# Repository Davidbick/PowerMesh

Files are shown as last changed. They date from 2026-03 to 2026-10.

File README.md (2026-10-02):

# PowerMesh: PLC Smart Home
PowerMesh is a smart home system that uses power line communication (PLC) instead of Wi-Fi to connect devices, enabling more stable and secure control over existing electrical wiring. It integrates Matter and Home Assistant to support cross-platform device control while exploring IP-based communication over power lines. 

## Project Architecture 
PowerMesh leverages PLC communication to integrate a Matter-based protocol built atop IEEE 1901.2. The user via our protocol can communication with one of our "hubs" to control an LED bulb at the other end of the Powerline.

Our user interacts with Home Assistant which transfers the commands via the ST8500 and STLD1 chips. The commands control the state of the endpoint lightbulbs and has the option to scale to various other receiver hubs connected to the powerlines.

## Task Designation:

1) PCB Design : Bryan, Daniel
- **Goal:** Contribute to PCB design of the PLC hub on the analog and digital boards to create a complete board design with both aspects.

2) Perf Board, ST IC Prototyping: Logan, David
- **Goal:**  Have code functionality with ST8500 and STLD1 chips using the STM32F4 so to have groundwork for software integration on PCB.

3) Home Assistant Setup: Steven
- **Goal:**  Have the Home Assistant platform working with STM32 and temporary endpoint (RPI4) to seemlessly integrate into design.

## Completed Work: Pre-Alpha Build

- Principal component research. We've narrowed our options to the ST8500 and STLD1 chips that powered a ST PLC development board.
- We've started PCB design on the hub infrastructure. Mostly on the digital side of the board with the STM32F4, ST8500, and STLD1.
- Started STM32 bring-up by writing and testing basic code for UART and peripherals without having the final hardware. Also planned out how the STM32 will communicate with the ST8500.

## Completed Work: Design Prototype
- We've completed schematic design for our analog and digital board with plans to complete layout before the beginning of next semester.
- We've integrated Home Assistant wirelessly with our RaspberryPi host device with plans to complete wired integration with an LED circuit.
- We've narrowed our software scope to the G3 stack after ST confirmed indirect IEEE 1901.2 compatibility. We'll have ST8500 integration before the beginning of next semester.

## Completed Work: Beta Build
- Home Assistant TUN interface
- PCB Digital Designs
- PCB Analog Designs

# Build Instructions
- Install Home Assistant OS on RaspberryPi, and connect GPIO pins to the appropriate serial protocol
- Use local address of Home Assistant server to visit Webpage and control added Home Assistant devices

# List of Known Bugs:
- PLC functionality has yet to be thoroughly tested with other components which will be a large endeavor
- The TUN interface and the Raspberry Pi-to-STM32 bridge currently require manual startup after the Raspberry Pi boots.
- STM32-to-ST8500 communication has not yet been integrated into the PowerMesh packet path.

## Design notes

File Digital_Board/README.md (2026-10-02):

# PowerMesh: PLC Home Digital PCB

This folder contains information related to the digital parts of the PLC hub board; more specifically the non coupler circuitry.

## Files
- `Digital_Board` contains the KiCad design files for Schematic and PCB layout
- `General_ST_Docs` contains ST chip information that would be useful to navigate the project
- `Programming_Docs`: Programming Docs on how to program the chip

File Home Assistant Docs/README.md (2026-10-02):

# Home Assistant

Home Assistant (HA) is an open-source software that will act as the hub to connect with the smart devices. We have Raspberry Pi OS x64 for the RPI3 on our microSD. From the RPI OS, we have a HA Docker.

## How it will be implemented

Using the RPI3 of the previous group, a microSD card housing HA Docker using RPI OS will be inserted into the RPI3. The RPI3 will be powered on using a micro USB and an ethernet cable will be connected to the RPI3 and a router. Once everything is connected, powered on, and the configuration is all set, the HA dashboard can be accessed. Commands will be sent via HA, and the statuses of the smart devices connected will also be sent to HA via the RPI hub. This should be done via using the Matter standard.

## Current bugs

- MicroSD we are using might be degrading. It was having write problems when trying to install RPI OS x64.

## Work completed

- Able to send a command from HA to a Matter-enabled smart bulb, which changed its color (Matter over Wi-Fi)
- Migration to RPI OS x64
- Design of Matter transportation

## Planned work

- Make RPI3 send the command out through UART instead of Wi-Fi (might have to disable Bluetooth, which might cause a problem for comissioning new Matter-enabled smart devices on to HA)
- Connect the RPI3 and STM32 via SPI so that the RPI3 sends the command to the STM32
- Get a ESP32 S3 dev kit that has enough RAM to store the Matter SDK via esp-matter. This will act as a DIY Matter-enabled smart bulb. Turn off wireless capabilities except Bluetooth (used for comissioning new smart devices). Test if Matter commands can control the RGB LED on it via PWM

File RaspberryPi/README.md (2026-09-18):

# PowerMesh Raspberry Pi Bridge

This directory contains the Raspberry Pi side of the PowerMesh transport.

It bridges Linux IPv6 traffic from a TUN interface to the STM32 using the existing PowerMesh UART framing protocol.

## Setup

Clone the repository on the Raspberry Pi:

```bash
cd ~
git clone https://github.com/Davidbick/PowerMesh.git
cd PowerMesh
```

Install the required Python support:

```bash
sudo apt update
sudo apt install -y python3-venv
```

Create the virtual environment and install dependencies:

```bash
python3 -m venv RaspberryPi/.venv

RaspberryPi/.venv/bin/pip install \
    -r RaspberryPi/requirements.txt
```

## Connect the STM32

Connect the STM32/Nucleo to the Pi over USB.

Find its serial port:

```bash
ls -l /dev/serial/by-id/
```

or:

```bash
ls /dev/ttyACM*
```

If serial permissions fail:

```bash
sudo usermod -aG dialout "$USER"
```

Then log out and back in or reboot.

## Create the TUN Interface

Make the setup script executable once:

```bash
chmod +x RaspberryPi/setup_tun.sh
```

Run:

```bash
./RaspberryPi/setup_tun.sh
```

This creates:

```text
Interface:  powermesh0
Pi address: fd00:706d::1/64
MTU:        1280
```

Verify:

```bash
ip -6 addr show dev powermesh0
```

and:

```bash
ip -6 route get fd00:706d::2
```

## Run the Bridge

Start the TUN/UART bridge:

```bash
RaspberryPi/.venv/bin/python \
    RaspberryPi/tun_uart_bridge.py \
    /dev/ttyACM0
```

Leave this running.

## Test

From another terminal on the Pi:

```bash
ping -6 fd00:706d::2
```

**The ping will not succeed yet because the STM32 does not currently generate an IPv6 reply.**

The bridge should show:

```text
TUN -> UART: seq=1, <bytes> bytes
UART ACK: seq=1, status=0
```

## Normal Use After Reboot

After rebooting the Pi:

```bash
cd ~/PowerMesh

./RaspberryPi/setup_tun.sh

RaspberryPi/.venv/bin/python \
    RaspberryPi/tun_uart_bridge.py \
    /dev/ttyACM0
```

## Updating

Pull the latest PowerMesh code:

```bash
cd ~/PowerMesh
git pull --ff-only
```

## Current Status

PowerMesh currently supports:

```text
Matter Server / Linux IPv6
        ↓
powermesh0 TUN
        ↓
Python TUN-UART bridge
        ↓
STM32
        ↓
UART ACK

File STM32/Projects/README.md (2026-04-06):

# STM32 Bring-Up

This sets up the NUCLEO-F446RE environment.

## What This Does

- Builds STM32 project using **CMake + VSCode**
- Verifies:
  - LED blink
  - UART transmit

## Required Tools

Install the following:

- STM32CubeMX
- arm-none-eabi-gcc
- CMake
- VSCode + Extensions
  - C/C++, CMake Tools, Cortex-Debug
- OpenOCD
- STM32CubeProgrammer

## Build Instructions

From project root:

```
cmake --preset Debug
cmake --build --preset Debug
```

## Hardware Test (When Board Arrives)

1. Plug in NUCLEO-F446RE via USB  
2. Start debug in VSCode  
3. Verify:
   - Breakpoint at `main()` works  
   - LED blinks  
   - UART prints over serial terminal  

- Next steps:
  - SPI bring-up  
  - STM32 ↔ ST8500 communication

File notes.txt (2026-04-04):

# PowerMesh Smart Home

Task Designation:

1) PCB Design : Bryan, Daniel
- Goal: Have progress on the PCB design aspects of the project so that we can present either a complete schematic or a thorough prototype so that we can order it first thing 2nd semester.,
- I'm planning on having an STM32 board and a PLC board with the ST8500 and the STLD1 chips that will house the coupling circuit.,
- I think splitting both boards would be a good idea so Daniel can likely work on the PLC board and I'll join once I finish the STM32 board which should be easier.,

2) ST setup: Logan, David
- Start communication between the 3 st chips using the PERF boards robert bought/already has.,
- Connect to the STM devboards and try to drive the ST8500 and the STLD1. While we won't be connected to the powerlines we can test functionality of the chips and start designing aspects of the coupling circuit potentially.,
- Goal: Have basic code functionality with the stm chips so that we can re-use that code on the final design with the PCB or in a robust breadboard testing.,

3) Home Assistant Setup: Steven
- Goal: Have the Home Assistant platform already working but with STM32 so we can just swap in the code once we get the PLC stuff working.,
- Specific Goals: Connect STM32 to Rpi4 with any serial communication (not sure if this will be the final method), Have home assistant interact with the bulb already MAYBE( might be harder than expected but we have bulbs to use).,
- This also allows someone to get substantial work done with the STM32 Nucleo and the Rpi4 that the last team left.,
- Dr. Del Rocco mentioned Home Assistant and I figured we could start work on this so we can have something substantial to show in the presentation.
- The benefit with on working with this, is once the nucleo arrives you should have everything to work on this.

For the STM32 development the workflow I'm familiar with is through vscode but if you want to use a different IDE that's okay, I just don't know what's going on with those.
The stuff you need is:

-STM32MX: This is the code generator with a GUI interface that is used for the ST MCUs. You should be able to choose our stm32f4 MCU and then it'll generate the code based on the peripherals you selected in the .ioc file. This should be a standalone download and make sure to use cmake as the build system at the last page before "generating project". You should be able to generate your .elf file this way.

OpenOCD: This is the server that you'll instantiate on your PC to communicate with the debugger on the nucelo board. There should be installation settings on their website. In Vscode you should be able to use the config files in the.vscode folder to run the openocd server and connect the debugger.

If you're debugging in VScode I recommend using the cortex-debug extension to set all this up. I've done this on linux a couple times but never on windows so I might be useless there. You should be able to connect to any IDE with Cmake and it gets rid of all that stmcubeide abstraction so you understand what's going on better.

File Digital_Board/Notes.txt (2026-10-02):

- VSS is the digital ground, VSSA is the Analog ground (DAC/ADC)
    -Not sure what the requirement is for this, aka will we need this? Look at the evalboard

-VDD is +3.3V for the MCU. VBAT is something else with an external battery but we can use +3.3v for it.

-Decoupling capacitors are used to place small energy storages along the MCU so that it doesn't rely on main battery.
    - 1 Decoupling-capa(100n F) per VBAT and VDD. Extra 10 uF at the end (volt decoupling)

-WTF is a fertite bead

- Look at the SPDT more for the BOOT0. I'm not exactly sure how this works.

- DO WE NEED USB if we have the UART?

-24 MHz for USB, just in case? FINISH OSCILLATOR

- Why is the USB shield NC/
-Check USB for resistors that I see on all other designs.

-GPIO6/7 are the RX and TX (HOST_IF1-4 are the UART)
    - Use USART2 asynchonrous on our design

- Add ferite bead to the regulator to reduce noise

-

Questions:
 - What is the UART/USB bridge for if USB is connected to the microcontroller?

TODO:
1) Confirm the Pitch for the STM32 microcontrollers
2) The Oscillator capactiors are WRONG!!!!

Slide 7:
	-Project is in the realm of research
	- PLC standards are not new, and are still widely used for smart metering technologies
	- However the standards have been largely dormant since the early 2010s. Which is in-line with the various ST chip options and their respective development kits.
	
	- Prior X10 adapters were a home standard for PLC communication between devices. But when wireless technologies blew up they rapidly shortened their usage.
	- Existing standards are G3-PLC, PRIME, and IEEE 1901.2
		- Difference is IEEE 1901.2 is lower stack protocol compared to GL3 that does RF communication

Slide 8:
	- Our initial research focused on research on the available resources and how to integrate them into our hub system.
	- Matter and Home Assistant are wide spread technologies which are tested we need to apply both of them.
	
	- The current state of the project is split into multiple groups: PCB design, software integration, and application design with HA
	- Our done metrics are the entirety of the research and schematic design for the separate boards. With software integration for our chosen chipset.
	
Slide 9:
	- Not going to go through everything but main aspects of thedigital board.
		- SWD for debugging
		- 2 UART channels as per existing EVAL kits
		- USBC for any integration with a desktop computer
		- External oscillator
	- STM32 to St8500 male pins
	- Access to SPI and I2C channels in case
	- Basics like reset buttons and LEDs

Pawpilot:
-

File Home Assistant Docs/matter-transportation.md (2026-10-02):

# Matter Transportation
There are various ways to transport the Matter payload to the Matter enabled end-device. Here are some options and some possible notes on how to implement them using the resources we have.

## Option 1: Create Matter Payload at the End
1. Capture the Home Assistant (HA) command that will be turned into a JSON. This would mean capturing the Matter Server WebSocket API [GitHub Documentation.](https://github.com/matter-js/matterjs-server/blob/main/docs/websockets_api.md?utm_source=chatgpt.com) This could be accomplished by using a proxy between HA and the Matter server, since the Matter server constructs the Matter payload.
2. Parsing of the command might be needed. Some essential fields to keep are node_id, endpoint_id, cluster_id, command_name, and payload (along with its contents). Others may also be necessary. Create the JSON. According to the documentation on point 1, device_command has all of this information.
3. Use a device with Matter SDK to dynamically create a Matter payload using the JSON.
4. For the Matter payload to actually get on the end-device, use an ethernet cable or make the end-device be the device that create the Matter payload for itself.

## Option 2: Point to Point Protocol (PPP)
1. Get Home Assistant on the RPI3 using linux. HA OS would have resitrictions that would make having PPP to automatically frame the Matter payload difficult.
2. Matter is IPv6. Use PPP to frame those IPv6 packets so that it can be sent serially, like through UART. Can also be used with SPI, but SPI is naturally more difficult. PPP essentially frames the IPv6 packets that contains the Matter payload.
3. Use UART to send the framed IPv6 packets from the RPI3 to the STM32.
4. Use UART/SPI to keep transporting everything. Besides the end-device, everything should just be transport.
5. Since we framed the IPv6 packets, it would have to be deframed somewhere. This would be at the end.

## Option 3: Ethernet Cable Everything
1. Simply have all devices have ethernet ports to transport the Matter payload, since Matter commands can be transported using ethernet. Also solves problems with Matter multicast (RPI3 communicating with multiple devices) and discovery (mDNS to announce that the device is back if power goes out). Makes sure that everything can handle IPv6 and ethernet compatibility.

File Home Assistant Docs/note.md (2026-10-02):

# Note
This file contains information about Home Assistant, how it is used, and how it works with our hardware.

## HA Initialization
When RPI is ready, enter this in a browser:
"http://\<RPI3_ADDRESS>:8123"
If white screen with HA logo, enter this in a browser:
"http://\<RPI3_ADDRESS>:4357"
If everything is green, then the RPI is being bottlenecked due to its limitations. Wait like 20 minutes before entering the other URL into a browser (close all HA instances so that the browsers won't take resources from the RPI).

## Adding Devices (old)
Adding matter device
open HA app -> settings -> device & services -> Search and select "Matter" -> use official matter server (box selected) -> scan QR code or hold phone near Matter device -> device should be connected after naming it

## Adding Home Assitant Docker to Raspberry Pi OS x64 (for RPI3) (CURRENT)
# Getting Raspberry Pi OS on a microSD
1. Select Device, OS, storage, create an account, and setup localisation
2. Skip Wi-Fi
3. Enable SSH
4. Write to the MicroSD

# Getting Docker (run these commands)
1. sudo apt update
2. sudo apt install ca-certificates curl
3. sudo install -m 0755 -d /etc/apt/keyrings
4. sudo curl -fsSL https://download.docker.com/linux/debian/gpg -o /etc/apt/keyrings/docker.asc
5. sudo chmod a+r /etc/apt/keyrings/docker.asc
6. echo \
  "deb [arch=$(dpkg --print-architecture) signed-by=/etc/apt/keyrings/docker.asc] https://download.docker.com/linux/debian \
  $(. /etc/os-release && echo "$VERSION_CODENAME") stable" | \
  sudo tee /etc/apt/sources.list.d/docker.list > /dev/null
7. sudo apt update
8. sudo apt install docker-ce docker-ce-cli containerd.io docker-buildx-plugin docker-compose-plugin
9. sudo docker run hello-world
10. You should get "Hello from Docker!" from step 9 if Docker is working.

# Getting HA (run these commands and follow instructions)
1. mkdir -p ~/homeassistant/config
2. mkdir -p ~/homeassistant/matter-server
3. cd ~/homeassistant
4. nano ~/homeassistant/compose.yaml
5. In the opened file, put the contents of compose_yaml.txt, which is found in the GitHub repo in the same directory as this Markdown file.
6. Save (ctrl + s) and exit (ctrl + x)
7. cd ~/homeassistant
8. sudo docker compose up -d
9. sudo docker compose ps
10. The previous command should show that HA is running. If there is a message about Bluetooth, ignore it.
11. In a broswer, type in "http://\<RPI3_ADDRESS>:8123". You can use "hostname -I" to find the address in the SSHed terminal, which should be the first one.
12. Use "sudo shutdown -h now" to turn off the Pi when shutting it down.

# Getting Matter Server (run these commands and follow instructions)
1. mkdir -p ~/homeassistant/matter-server
2. nano ~/homeassistant/matter-server/compose.yaml
3. In the opened file, put the contents of matter_server_compose_yaml.txt, which is found in the GitHub repo in the same directory as this Markdown file.
4. cd ~/homeassistant/matter-server
5. sudo docker compose up -d
6. sudo docker compose ps
7. The previous command should show that matterjs-server is running.
8. sudo docker compose logs -f
9. Previous command shows logs for the matter server. Do (ctrl + c) to exit logs.
10. sudo docker logs matterjs-server
11. If the previous command show that the matter server is failing due to "EACCESS: permission denied" do the following (or skip to 18):
12. cd ~/homeassistant/matter-server
13. sudo docker compose down
14. ls -ld ~/homeassistant/matter-server/data
15. docker run --rm --entrypoint id ghcr.io/matter-js/matterjs-server:latest
16. Take note of the uid and gid.
16. sudo chown -R \<UID>:\<GID> ~/homeassistant/matter-server/data
17. If there is no ~/homeassistant/matter-server/data, make it. (mkdir -p ~/homeassistant/matter-server/data), then sudo chown -R \<UID>:\<GID> ~/homeassistant/matter-server/data
18. cd ~/homeassistant/matter-server
19. sudo docker compose up -d
20. sudo docker compose logs -f
21. sudo docker compose ps

# Adding Matter in HA
1. Open HA
2. Settings -> Devices & services -> Add integration
3. Search and click the ones that says "Matter" and wait for it to finish.
4. For the url, put "ws://localhost:5580/ws".

# Debugging
1. No username
If there is no username, it should default to "pi".
For our current project, the username is "powermesh".
2. SSH not responding (please read fully)
In a terminal such as Powershell, do "arp -a". The address should start as 192.168. It could also be something different.
Try to SSH into each one with "ssh \<USERNAME>@\<ADDRESS>".
The address for a Pi should respond with connection refused, while the others will have an unknown error. If multiple has connection refused, use other methods to identify the Pi.
Take out the microSD card and check if it has a file titled "ssh" with no file extension.
If there is no "ssh", correctly add one, which should enable SSH. If the address is still giving problems, use "ipconfig" in a terminal. Get the gateway address, and in a broswer type "http://\<GATEWAY>". This should list all connected devices. The one we are looking for is "PowerMesh". This will show the address for the Pi.

## Adding HA OS to a microSD (DEPRECATED)
RPI Micro SD configuration:
https://www.home-assistant.io/installation/raspberrypi/
Notes from the link:
1. Download RPI Imager and launch it
2. Select RPI3 as device
3. Select Other SPECIFIC-purpose OS (OS Section)
4. Select Home Automation and select Home Assistant (OS Section)
5. There should only be one HA option to choose from. Select it (OS Section)
6. In the storage section, select the Micro SD we are writing it to
7. Click next and it should begin writing HA OS to the Micro SD

## RPI Debugging
RPI Debugging:
1. Check if the RPI is receiving enough power. This can be checked by seeing a constant red LED on the RPI. If it is flickering, the RPI3 is not receiving the constant power it needs.
2. To see if HA is working, look if there is green flickering on the RPI. If there is green flickering, then HA is working.
3. If there is a white screen with HA logo only when doing http://homeassistant.local:8123/, use http://IP_ADDRESS:8123 or the app instead. This is likely due to browser cache issues or hardware limitations of the RPI3.

## HA Companion App
Home Assistant Companion App Download & Instructions:
https://companion.home-assistant.io/docs/getting_started/

Note: This may be for HA OS, and instructions for HA Docker may be different.

### Misc
Home Assistant Green:
https://www.home-assistant.io/green/

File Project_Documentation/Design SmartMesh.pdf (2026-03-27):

### PowerMesh – Design Plan

Project Title: PowerMesh – Matter-over-PLC smart-home infrastructure
Team Members: David Bickram, Steven Pham, Bryan Gonzalez, Logan Dukes, Daniel Goldenberg

Date: 3/24/2026

Terminology:

- PLC → Power Line Communication
- MCU → Microcontroller Unit
- Home Assistant → Open Source Software with Matter Integration. Not to be confused with an actual home assistant like Alexa

### 1. Introduction

### 1.1 Purpose / Need

PowerMesh is a solution to the wireless mesh instability problem. Convenience has been a guiding factor in smart home products, with wireless systems like Thread and Wi-Fi being the most widely adopted technologies. However, the wireless infrastructure isn’t without its faults, with difficulty of installation, network instability, and security concerns being the most prominent.

All these issues are a result of the always-on-network conundrum, where all smart devices must always be connected to the wireless network, and once network issues occur, the entire smart infrastructure goes down. PowerMesh hopes to tackle this by having PLC-based infrastructure that won’t require wireless connectivity, which in return will simplify smart device adoption for consumers by avoiding the barrier of wireless connectivity entirely.

### 1.2 Domain & Prior Art

The field we are specifically targeting is the smart home industry, where wireless technology is prevalent and the product installation is an annoyance. Examples of products in the space are wireless lights (bulbs, strips, and lamps) and home assistants like Alexa.

More specific to our product methodology, PLC technologies that exist but are not often used are X10 connectors [1]. This protocol was a simplified control system for lights in a house. Issues that plagued the technology were a lack of encryption and addressing capabilities, with a limit of 256 devices. This standard is quite antiquated, but it hasn’t been improved upon in decades, so we hope to implement a modern and stable alternative.

### 1.3 Impact & Risk Assessment

Our project will improve societal standards for consumer-grade products by giving consumers control of their smart device networks at home by providing an open hardware and software alternative. We are tackling large infrastructural issues with our project, so potential risks could be compromising consumer security through development oversights or not having reproducible results with the various smart devices in existence, which could limit our adoption.

Economically, our project provides developers with a way to produce low-cost microcontroller systems with existing powerline infrastructure, with those low costs hopefully being reflected in consumer pricing. With our emphasis on using PLC in our project, we are leveraging the existing technology around homes, minimizing the need for new infrastructure that could impact the environment. Social impact is a driving point in our project, specifically encouraging user privacy in our infrastructure as we move away from the more vulnerable wireless systems.

### 2. Statement of Work

### 2.1 Project Overview

### 2.1.1 General Specifications

- Have a PLC-based infrastructure of smart devices that can be remotely controlled via Home Assistant interface with Matter
- Target Smart Device: LED Lightbulbs (aka. multiple receivers)
- The client and server side will use the ST8500 IC to communicate via the powerlines sending data to configure the smart home devices
- Matter: Allows operation of multiple devices from different manufactures such as Google, Apple, and Amazon. [2]. This allows us to integrate with products that dominate the market and new arriving products that will follow suit with Matter.

### 2.2.2 Hardware Requirements

- Client-sided: Use existing smart device circuitry and integrate our custom PLC/ST circuitry into the product, essentially creating our own lightbulb from the existing bulb circuitry. The goal is to have multiple receivers connected to the same transmitter. Uses ST8500 and STM32.
- Server-sided: Integrate PLC/ST circuitry with either a raspberry pi or desktop computer serially. Create a plug-and-play hub with USB. This will communicate with the Home Assistant application to the single/various receivers.
- Networking: Integrate TCP/IP-style communication between devices targeting 3-5 byte per second payload speeds for our LED lightbulb following the IEEE 1901.2 standard. We will be using I2C-style node addressing to communicate with the different receiver nodes using our custom standard.
- Power Consumption: Targeting less than 33kW a year including the LED bulb (13 kW a year) [4] and our ST8500 (20kW) [5]

### 2.1.3 Software Requirements

- MCU:
- Languages: C, C++
- Frameworks: TCP/IP (FreeRTOS/ LWIP), FreeRTOS
- Build Systems: Cmake, Make
- User-Application:
- Languages: Python
- Frameworks: Home Assistant
- General:
- Linux (Debian) for hub system
- ARM cross-compiler targeting ARM Cortex-M ST8500/STM32

### 2.2 Secondary Features

- Thread Integration:Matter supports Thread, which allows for wireless communication with certain devices that our technology could potentially not reach. This allows the possibility of having a smart home using both wired and wireless smart devices.

### 2.3 Milestones and Task Allocation

- Information gathering (This Week & Spring Break)
- Research previous groups efforts
- Determine required hardware components (STM32, STM8500, etc.)
- IEEE 1901.2, Matter, Home Assistant
- Prototype Bring-up (March - April)
- Acquire our hardware development kits (STM-Nucleo/Evalboard)
- Breadboard the basics required for having a communication interconnect between our server and the client prototype smart device
- Have basic Home Assistant integration with some compatible software
- Validation (Throughout Design Process)
- Testing code
- Documentation
- Matter PLC communication standard Design (Fall Semester)

- Final Prototype Targeting (Fall Semester)
- Establish connection with industrial smart bulb and properly control via PLC infrastructure
- Have our smart device rendition PCB
- Thread Integration (Secondary Goal)

### 2.4 Work to Complete This Semester

1) Have a clear demonstration of sending and receiving packets on both endpoints
2) Some sort of client-side equipment functions with received packets
3) Client-side equipment works with transferable interface

### 2.5 Work to Complete At End of Term

1) Multi-colored lightbulb works with packet data
2) Working with Home Assistant
3) Custom PCB integration for lightbulb example
4) Established communication protocol and submit Matter certification

### 3. Deliverable Artifacts

Smart Device Design/Circuitry: This artifact will either be our client hardware connected to the existing circuitry of an LED bulb or a custom LED bulb/hardware that can interact with the hub. Once we are confident in its capabilities, we will integrate it with existing lightbulb technology. The software for the device will be open-source, and the hardware design will be available to replicate on existing Matter smart devices.

Hub Design: The hub design is central for the PLC network; it will control communication between the various devices on the network. With the hub we plan on having a desktop-oriented design for testing purposes, which we’ll move to custom PCB hardware for the final product. For redistributing this hub, we would need to recreate a replica of the hardware, and its software will be open-source.

Home Assistant Interface: This aspect of the project connects the hub and the user-application interface that’ll use Home Assistant with the Matter protocol. This will be usable via a desktop computer or a mobile device. We’ll distribute this via a standard HTTP website that we can test and then improve upon with new plugins. There are no concerns with the Home Assistant software’s availability, as it's constantly being updated, and its plugin flexibility allows people to expand compatibility to their own smart device products.

### 4. Mockups

### 4.1 Interfaces

For PowerMesh, the singular interface is expected to be the Home Assistant control platform running on the hub. The rest of the project will rely on the plug-and-play aspects we hope to create for our users with our hub.

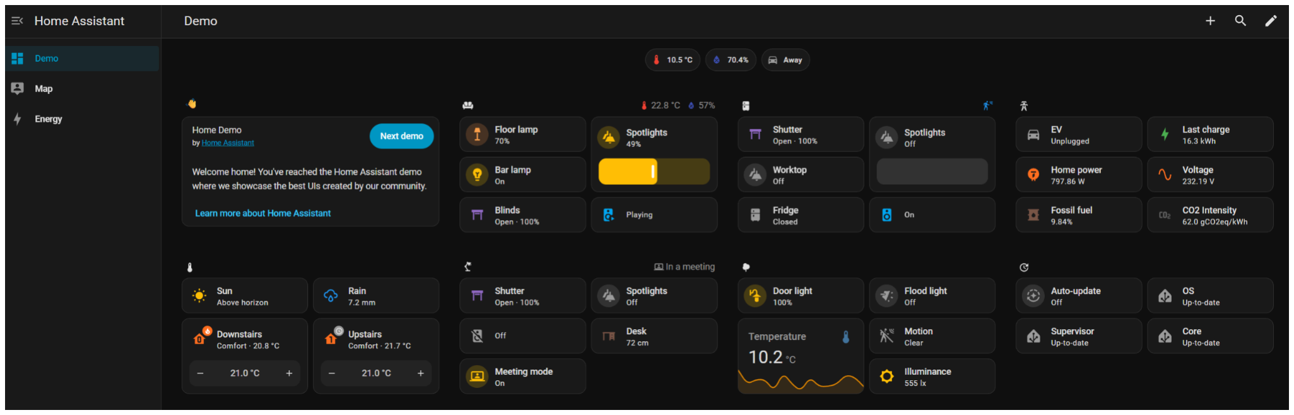
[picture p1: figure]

Figure 1. Home Assistant Dashboard

### 4.2 Systems

The project contains three major subsystems: the hub, the PLC network path, and the
wall node. The hub manages commissioning, user commands, and logging. The PLC path carries framed traffic across the mains and reports link-health data. The wall node hosts the device application and maps it to the transport.

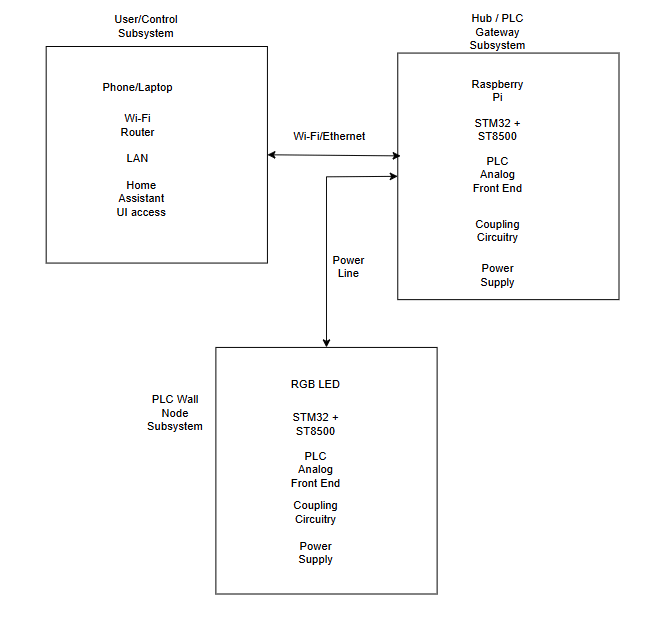
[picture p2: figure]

Figure 2. Subsystem Hardware Components

### 4.3 Networking Model

The PowerMesh networking architecture consists of a hub communicating with embedded wall nodes over PLC, with Home Assistant on the Raspberry Pi serving as the primary control interface. The communication architecture diagram illustrates the end-to-end device interaction across the system, while the protocol layer diagram shows how application commands are translated through the Matter/IP and PLC layers into physical transmissions over the power line network.

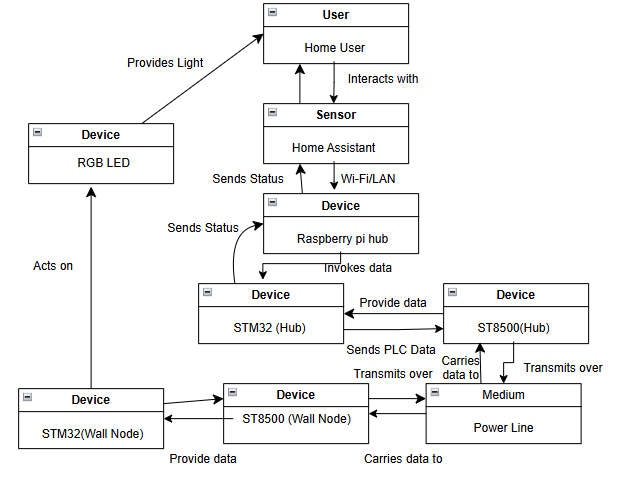
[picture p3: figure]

Figure 3. High Level Communication Architecture

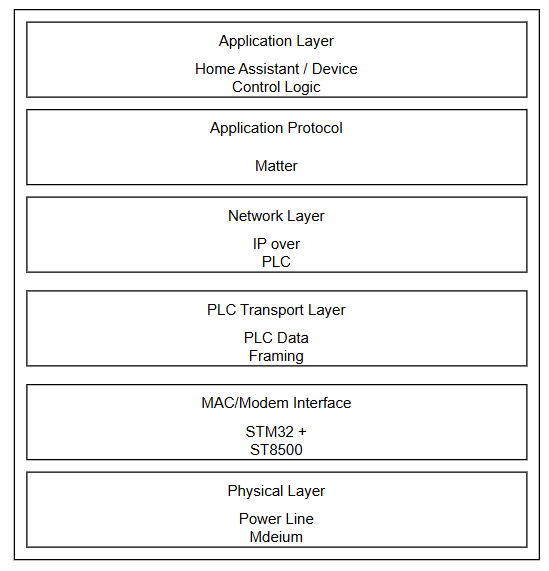
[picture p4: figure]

Figure 4. Protocol Layer Diagram

### 4.4 Storyboards

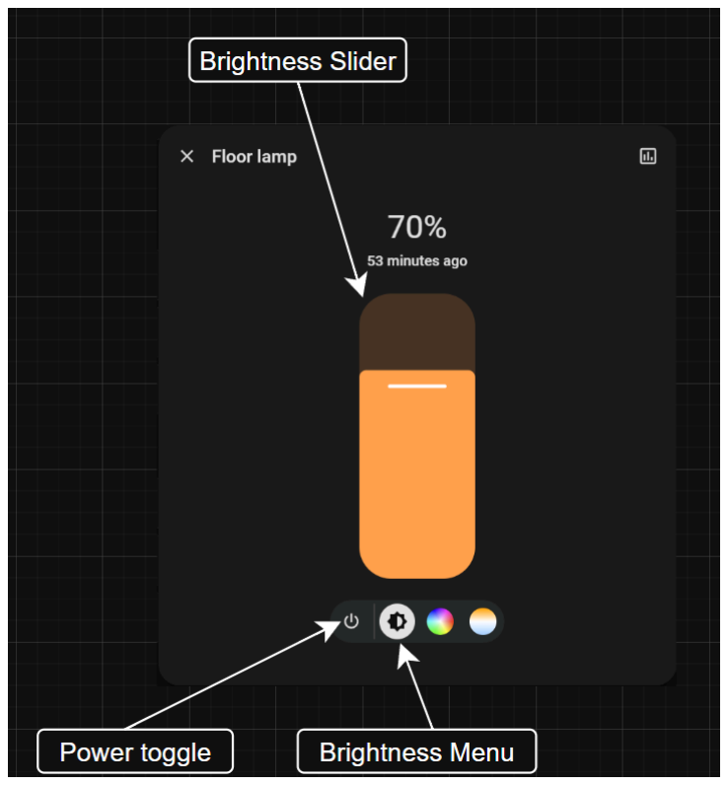
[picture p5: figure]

Figure 5. Home Assistant light brightness control

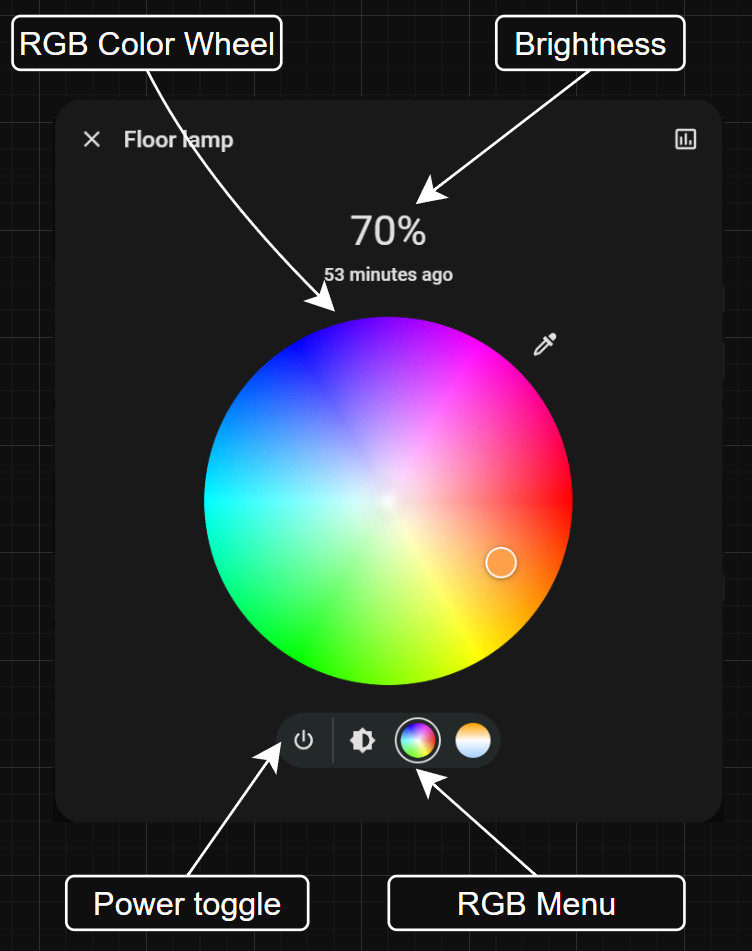
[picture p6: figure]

Figure 6. Home Assistant RGB color control

### 4.5 Draft Schematics

This schematic provides an overview of our MCU infrastructure that we’ll use on the smart device endpoint.

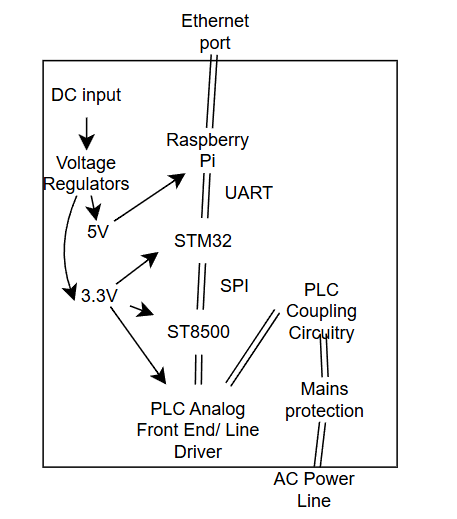
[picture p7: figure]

Figure 7. Schematic of the Hub

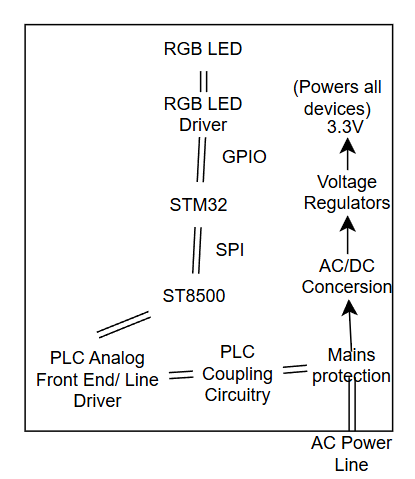
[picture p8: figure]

Figure 8. Schematic of the Wall Node

References
[1]“PLC01 Powerline Repeater X10,” X10.COM, 2020. https://www.x10.com/products/plc01 (accessed Mar. 12, 2026).
[2]“Matter FAQs | Frequently Asked Questions,” CSA-IOT.
https://csa-iot.org/all-solutions/matter/matter-faq/
[3] Home Assistant, “Home Assistant,” Home Assistant, 2019. https://www.home-assistant.io/
[4] “How Much Electricity Does A LED Light Bulb Use? [2025 Guide],” SolarTech, Aug. 22, 2025. https://solartechonline.com/blog/how-much-electricity-led-light-bulb-use/
[5] “ST8500 | Product - STMicroelectronics,” STMicroelectronics, 2024.
https://www.st.com/en/interfaces-and-transceivers/st8500.html#documentation (accessed Mar. 23, 2026).

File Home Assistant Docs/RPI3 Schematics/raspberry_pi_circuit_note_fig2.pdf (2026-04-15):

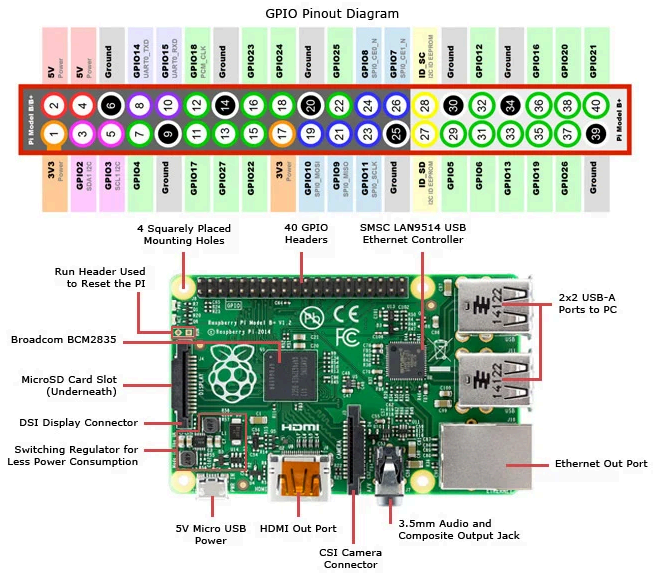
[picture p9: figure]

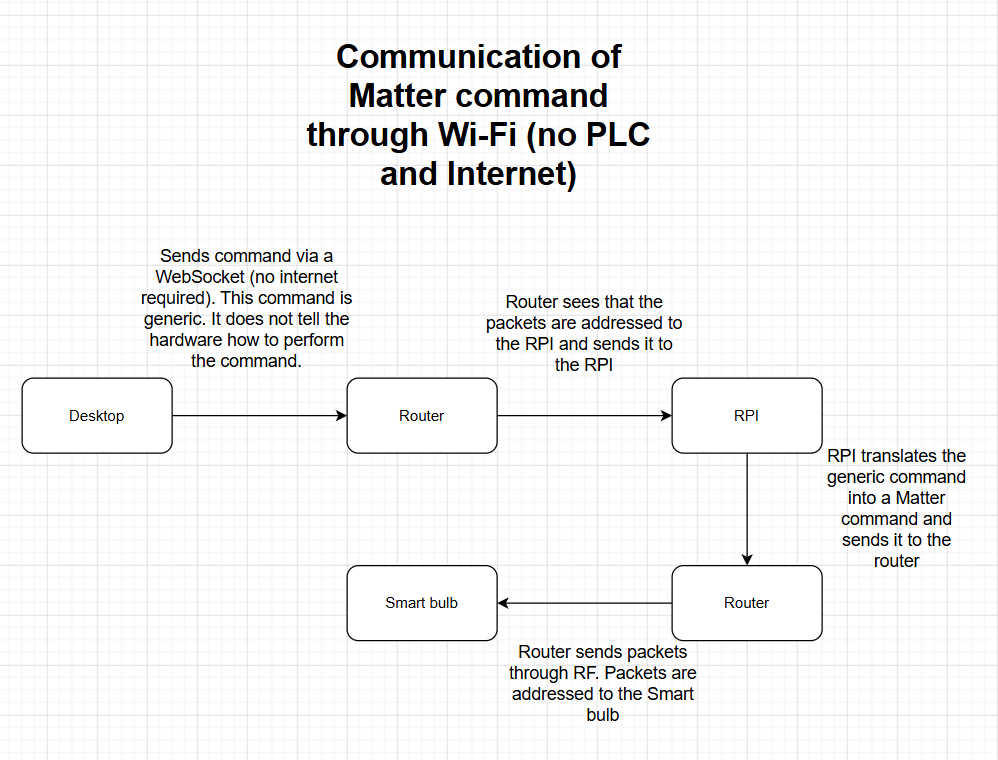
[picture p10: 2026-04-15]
Images/Communication no PLC.png

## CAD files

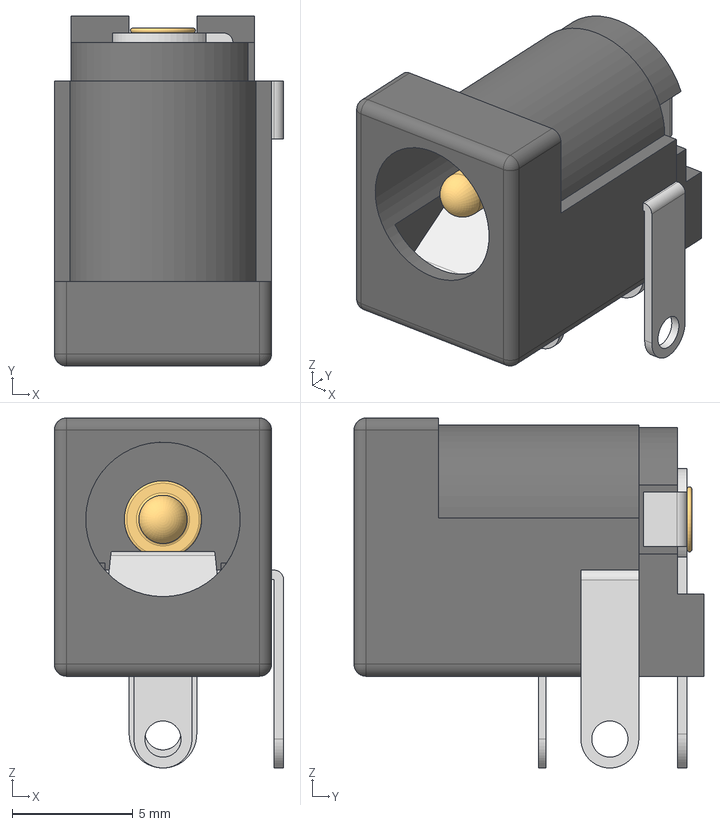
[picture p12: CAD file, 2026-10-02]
Digital_Board/Nonlibrary_Components/Project_Components/jack_694106301002/Download_STP_694106301002_rev1.stp
9.50 x 14.5 x 14.5 mm
6941xx301002
694106301002_PinContact
6941xx301002_Back
6941xx301002_PinContact2
6941xx301002_PinLame
6941xx301002_PinBis

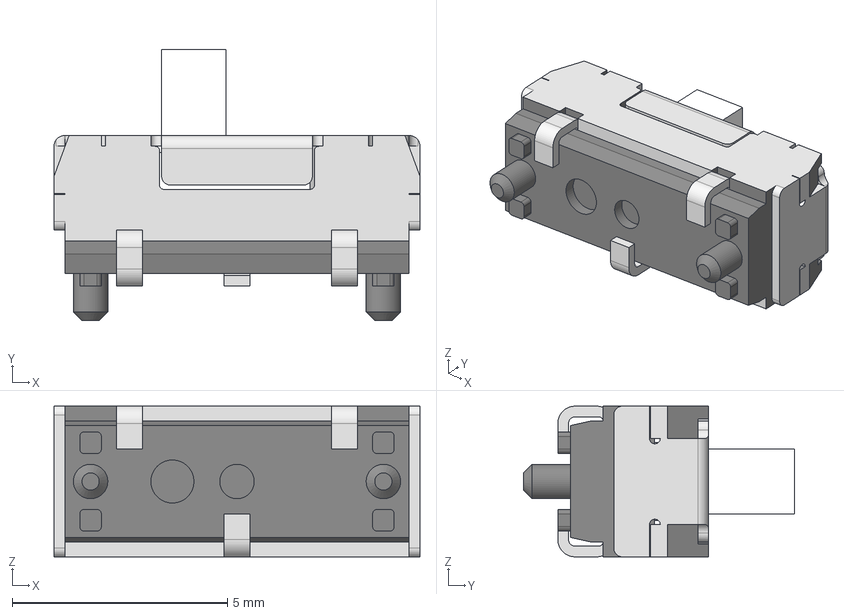
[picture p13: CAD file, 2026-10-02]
Digital_Board/Nonlibrary_Components/Project_Components/SWITCH_COPAL_CLSB12A01T/CL-SB-12A-01T.stp
8.50 x 6.30 x 3.50 mm
12A-01_c
2Top setting_s

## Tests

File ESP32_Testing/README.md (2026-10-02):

# ESP32 Testing
Used to test the Matter transport to see if a Matter endpoint receives the payload correctly.

Currently only supports ESP32-S3 DevKitC-1 v1.1 with the WROOM2 N32R16V
Using ESP IDF 5.5.5 and ESP Matter 1.6.0

Due to the various issues regarding dependency (of ESP IDF and ESP Matter), problems with commissioning, and menuconfig acting strange, an already made Matter light with the ESP32 S3 will be used to test if possible.

## Current Issues
1. Commissioning fails, so the device is not added to Home Assistant. It is unknown whether it is the ESP32 causing the problem or the Matter server/integration on the RPI.

## Current Progress
1. Creates the Matter endpoint
2. Has commissioning
3. Has different functionalites for the Matter device, such as turning in on, changing colors, etc.
4. State of the light should be reflected

## To-do
### Operation with Wi-Fi (To be completed first)
1. Verify that commissioning works properly (must connect to Home Assistant)
2. Verify that endpoint can be seen
3. Verify that updating the main program doesn't ruin the commissioning if it is already done
4. Verify that features such as turning on/off light and changing colors work
5. Verify if the state change is reflected on the Home Assistant card

### Without Wi-Fi (WIRED)
1. Enable UART functionality
2. De-frame the custom frame of the IPv6 packets
3. Have Matter take in the de-framed packets
4. Go through all functionality tests (1-5) from Operation with Wi-Fi, except this time it is wired

### Tests Completed
1. None

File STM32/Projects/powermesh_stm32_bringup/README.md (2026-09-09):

# PowerMesh STM32 UART Bring-Up

This STM32 project provides the initial PowerMesh UART transport used between the Raspberry Pi gateway and the STM32.

It implements a simple framed UART protocol with payload length, sequence number, and CRC checking.

## UART Configuration

The project uses USART2 with:

```text
Baud:       115200
Data bits:  8
Parity:     None
Stop bits:  1
Flow ctrl:  None
```

On the Nucleo board, USART2 is available through the ST-Link USB virtual COM port.

## PowerMesh Frame

A PowerMesh UART frame contains:

```text
+------+---------+------+----------+--------+---------+-------+
| Sync | Version | Type | Sequence | Length | Payload | CRC32 |
+------+---------+------+----------+--------+---------+-------+
```

Sync bytes:

```text
A5 5A
```

Current frame types:

```text
DATA = 1
ACK  = 2
```

Maximum payload:

```text
1280 bytes
```

The payload is treated as raw data by the UART layer. For the PowerMesh IP transport, a `DATA` payload can contain one raw IPv6 packet.

## Build

From:

```bash
cd STM32/Projects/powermesh_stm32_bringup
```

Configure if needed:

```bash
cmake --preset Debug
```

Build:

```bash
cmake --build build/Debug
```

The resulting firmware image can then be flashed to the STM32.

## Test the UART Link

Connect the Nucleo board to the host computer over USB.

Run the UART test from the PowerMesh repository root:

```bash
python3 \
    STM32/Projects/powermesh_stm32_bringup/Tools/uart_frame_test.py \
    /dev/ttyACM0
```

Expected result:

```text
Sent DATA: sequence=1
Received ACK: sequence=1
PASS
```

This verifies that framed, bidirectional UART communication is working.

The `ACK` confirms receipt of the PowerMesh UART frame. It is not a response to the contents of the payload itself.

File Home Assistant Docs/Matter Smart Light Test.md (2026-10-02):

# Matter Smart Light Test

This contains information about controlling a commercial Matter-enabled smart light bulb via Home Assistant (HA) which is on Raspberry PI OS.
This is for testing current configuration of HA and familarizing using HA.

### Smart Light used for Testing

We are using the Linkind Wi-Fi Smart Light Bulb A19 RGBTW that supports Matter.

## Commissioning the Smart Light
1) Factory reset the light bulb. Each brand has their own different ways to factory reset their devices. For our current light, we need to power on and off the light bulb several times. Each toggle should be between 0.5 to 1.5 seconds. The light bulb will shift through many colors before it is ready to pair.
2) Download the Home Assistant Companion App. Configure the app however you want so that it works.
3) Turn on Wi-Fi and Bluetooth.
4) On the app, click add a device, and make sure that Matter was selected for the device type.
5) Scan the QR code.
6) It should automatically commission now. To use the smart light, go on the app and change the state of the light. These changes should be physically shone on the light and on the app.

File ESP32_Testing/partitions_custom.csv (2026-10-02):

# Name | Type | SubType | Offset | Size
nvs | data | nvs | 0x9000 | 0x6000
phy_init | data | phy | 0xF000 | 0x1000
factory | app | factory | 0x10000 | 0x1F0000

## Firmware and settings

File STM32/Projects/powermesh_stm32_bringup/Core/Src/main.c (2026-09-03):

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
/* Includes ------------------------------------------------------------------*/
#include "main.h"
#include "spi.h"
#include "usart.h"
#include "gpio.h"

/* USER CODE BEGIN Includes */
#include "uart_frame.h"
/* USER CODE END Includes */


/* USER CODE BEGIN PV */
static uart_frame_t rx_frame;
static uint8_t ack_status = 0U;
/* USER CODE END PV */

void SystemClock_Config(void);
/**
  * @brief  The application entry point.
  * @retval int
  */
int main(void)
{

  /* MCU Configuration--------------------------------------------------------*/

  /* Reset of all peripherals, Initializes the Flash interface and the Systick. */
  HAL_Init();

  /* Configure the system clock */
  SystemClock_Config();

  /* Initialize all configured peripherals */
  MX_GPIO_Init();
  MX_USART2_UART_Init();
  MX_SPI2_Init();
  /* Infinite loop */
  /* USER CODE BEGIN WHILE */
  while (1)
  {
    /* USER CODE END WHILE */

    /* USER CODE BEGIN 3 */
     if (uart_frame_receive(&huart2, &rx_frame) == HAL_OK)
    {
        if (rx_frame.type == UART_FRAME_TYPE_DATA)
        {
            HAL_GPIO_TogglePin(GPIOA, GPIO_PIN_5);

            uart_frame_send(
                &huart2,
                UART_FRAME_TYPE_ACK,
                rx_frame.sequence,
                &ack_status,
                sizeof(ack_status)
            );
        }
    }
  }
  /* USER CODE END 3 */
}

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


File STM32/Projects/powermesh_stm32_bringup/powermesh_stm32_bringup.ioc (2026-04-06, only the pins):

Mcu.UserName=STM32F446RETx
PA13.GPIO_Label=TMS
PA13.Signal=SYS_JTMS-SWDIO
PA14.GPIO_Label=TCK
PA14.Signal=SYS_JTCK-SWCLK
PA2.GPIO_Label=USART_TX
PA2.Signal=USART2_TX
PA3.GPIO_Label=USART_RX
PA3.Signal=USART2_RX
PA5.Signal=GPIO_Output
PB10.Signal=SPI2_SCK
PB3.GPIO_Label=SWO
PB3.Signal=SYS_JTDO-SWO
PC1.Signal=SPI2_MOSI
PC13.GPIO_Label=B1 [Blue PushButton]
PC13.Signal=GPXTI13
PC14-OSC32_IN.Signal=RCC_OSC32_IN
PC15-OSC32_OUT.Signal=RCC_OSC32_OUT
PC2.Signal=SPI2_MISO
PH0-OSC_IN.Signal=RCC_OSC_IN
PH1-OSC_OUT.Signal=RCC_OSC_OUT

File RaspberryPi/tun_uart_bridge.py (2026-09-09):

#!/usr/bin/env python3

import argparse
import fcntl
import os
import select
import struct

import serial

from uart_frame import (
    MAX_PAYLOAD,
    TYPE_ACK,
    TYPE_DATA,
    read_frame,
    write_frame,
)


# Linux TUN definitions
TUNSETIFF = 0x400454CA
IFF_TUN = 0x0001
IFF_NO_PI = 0x1000


def open_tun(name: str) -> int:
    fd = os.open(
        "/dev/net/tun",
        os.O_RDWR,
    )

    ifreq = struct.pack(
        "16sH",
        name.encode("ascii"),
        IFF_TUN | IFF_NO_PI,
    )

    fcntl.ioctl(
        fd,
        TUNSETIFF,
        ifreq,
    )

    return fd


def is_ipv6(packet: bytes) -> bool:
    if not packet:
        return False

    return (packet[0] >> 4) == 6


def main():
    parser = argparse.ArgumentParser(
        description="PowerMesh TUN <-> UART bridge"
    )

    parser.add_argument(
        "port",
        help=(
            "STM32 serial device, for example "
            "/dev/ttyACM0 or /dev/serial/by-id/..."
        ),
    )

    parser.add_argument(
        "--tun",
        default="powermesh0",
        help="TUN interface name",
    )

    parser.add_argument(
        "--baud",
        type=int,
        default=115200,
        help="UART baud rate",
    )

    args = parser.parse_args()

    tun_fd = open_tun(args.tun)

    port = serial.Serial(
        args.port,
        baudrate=args.baud,
        timeout=1.0,
    )

    port.reset_input_buffer()

    sequence = 1

    print(
        f"PowerMesh bridge started:"
        f"\n  TUN:  {args.tun}"
        f"\n  UART: {args.port}"
        f"\n  Baud: {args.baud}"
    )

    try:
        while True:
            readable, _, _ = select.select(
                [
                    tun_fd,
                    port.fileno(),
                ],
                [],
                [],
            )

            #
            # Linux -> TUN -> UART -> STM32
            #
            if tun_fd in readable:
                packet = os.read(
                    tun_fd,
                    MAX_PAYLOAD,
                )

                if not is_ipv6(packet):
                    print(
                        f"DROP TUN: non-IPv6 packet "
                        f"({len(packet)} bytes)"
                    )
                    continue

                write_frame(
                    port,
                    TYPE_DATA,
                    sequence,
                    packet,
                )

                print(
                    f"TUN -> UART: "
                    f"seq={sequence}, "
                    f"{len(packet)} bytes"
                )

                sequence = (sequence + 1) & 0xFFFF

                if sequence == 0:
                    sequence = 1

            if port.fileno() in readable:
                try:
                    frame_type, rx_sequence, payload = read_frame(
                        port
                    )

                except (TimeoutError, ValueError) as error:
                    print(
                        f"UART frame error: {error}"
                    )
                    continue

                if frame_type == TYPE_ACK:
                    status = (
                        payload[0]
                        if payload
                        else None
                    )

                    print(
                        f"UART ACK: "
                        f"seq={rx_sequence}, "
                        f"status={status}"
                    )

                    continue

                if frame_type != TYPE_DATA:
                    print(
                        f"UART: unsupported frame type "
                        f"{frame_type}"
                    )
                    continue

                if not is_ipv6(payload):
                    print(
                        f"DROP UART: DATA payload is "
                        f"not IPv6 ({len(payload)} bytes)"
                    )
                    continue

                os.write(
                    tun_fd,
                    payload,
                )

                print(
                    f"UART -> TUN: "
                    f"seq={rx_sequence}, "
                    f"{len(payload)} bytes"
                )

    except KeyboardInterrupt:
        print("\nStopping PowerMesh bridge.")

    finally:
        port.close()
        os.close(tun_fd)


if __name__ == "__main__":
    main()

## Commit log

2026-03-29 initial files
    [05 - VIPer26_Comet_HV.DRL, 05 - VIPer26_Comet_HV.GBL, 05 - VIPer26_Comet_HV.GBO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]
2026-03-31 organized files and more
    [05 - VIPer26_Comet_HV.DRL, 05 - VIPer26_Comet_HV.GBL, 05 - VIPer26_Comet_HV.GBO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]
2026-04-01 pcb and notes
    [STM_PLC_Board.kicad_sch]
2026-04-04 prep alpha
    [STM_PLC_Board.kicad_pcb, STM_PLC_Board.kicad_sch]
2026-04-06 Initial STM32CubeMX build
    Using USART2, SPI2 and Green LED
2026-04-06 Initial build for the nucleo
    This blinks the led and sends UART message.
2026-04-07 Expand note.txt with Home Assistant setup instructions
    Added detailed instructions for setting up Home Assistant on Raspberry Pi and links for additional resources.
2026-04-07 Created ST8500 IC symbol
    [plc-pcb.kicad_pcb, plc-pcb.kicad_sch]
2026-04-07 Added ST8500 footprint
    [plc-pcb.kicad_sch]
2026-04-07 Created STLD1 symbol
    [plc-pcb.kicad_sch]
2026-04-08 to desktop
    [STM_PLC_Board.kicad_sch]
2026-04-08 st8500 manual stuff, binaries :(
    [STM_PLC_Board.kicad_sch]
2026-04-08 PLC high voltage rough draft
    [plc-pcb.kicad_sch]
2026-04-12 to pc
    [05 - VIPer26_Comet_HV.DRL, 05 - VIPer26_Comet_HV.GBL, 05 - VIPer26_Comet_HV.GBO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]
2026-04-13 new changes
    [STM_PLC_Board.kicad_sch, components.kicad_sch, st8500_board.kicad_sch]
2026-04-13 STM32 schematic done
    [STM_PLC_Board.kicad_sch, components.kicad_sch]
2026-04-15 Update note.txt with Matter device setup instructions
2026-04-15 made schematic folder for the RPI
2026-04-27 Update README.md for Design Prototype.
2026-08-24 added ST8500 connections
    [components.kicad_sch, stm32_st8500.kicad_sch]
2026-08-24 schematic done
    [STM_PLC_Board.kicad_sch, components.kicad_sch, stm32_st8500.kicad_sch]
2026-09-03 Add bidirectional USART2 echo test for STM32
2026-09-03 Add framed UART transport and test file
2026-09-06 added components
    [CL-SB-12A-01T.stp, STM_PLC_Board.kicad_sch, components.kicad_sch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]
2026-09-08 Add changes regarding how Home Assistant will be installed onto device
2026-09-08 Updated note.md to reflect usage of Raspberry Pi OS x64 with Home Assistant and Matter server. Still have to add Matter to HA. Add yaml files for configuration of HA and the matter server.
2026-09-09 Added TUN to RaspberryPi
2026-09-09 Added documentation for UART frames
2026-09-15 Add initial setup for ESP32 S3 testing of Matter endpoint.
2026-09-17 pcb changes
    [CL-SB-12A-01T.stp, Download_STP_694106301002_rev1.stp, STM_PLC_Board.kicad_pcb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]
2026-09-18 Update README with current status of PowerMesh
    Added current status section to README with details on PowerMesh support.
2026-09-22 Changed ESP32 testing. Will be using a Matter smart light for the ESP32 S3 that someone has already made since the current one is too confusing to fix now (commissioning issue). Commercial smart ligh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
    [partitions_custom.csv]
2026-10-06 ESP32 Matter light Working
    [partitions.csv, partitions.s31.csv, partitions_custom.csv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]
2026-10-14 Add systemd startup for TUN and UART bridge with STM32 reconnection
2026-10-15 Setup folder for wired ESP32 testing
2026-10-26 Added finished ESP32 code
2026-10-27 Added README for wired Matter
2026-10-28 Implement bidirectional UART IPv6 transport for wired Matter
2026-10-28 STM32-F4 Updated Configuration
2026-10-28 Configure F4 dual-UART peripherals and DMA
2026-10-28 Refactor F4 UART firmware
2026-10-28 STM32-G4 Configuration
2026-10-28 Update README to reflect Wired changes
    Removed descriptions about the wireless return and that there were no SDKconfig changes.
2026-10-28 Implement STM32-F$ packet forwarding
2026-10-28 Bring up STM32G4 firmware
2026-10-28 Implement STM32G4 packet forwarding
2026-11-10 Unify STM32G4 firmware for gateway and endpoint
2026-11-13 Configure STM32G4 peripherals for PLC integration
2026-11-13 Implement automatic ST8500 firmware loading from STM32.
2026-11-13 Added debug terminal for stm32 to st8500 flashing

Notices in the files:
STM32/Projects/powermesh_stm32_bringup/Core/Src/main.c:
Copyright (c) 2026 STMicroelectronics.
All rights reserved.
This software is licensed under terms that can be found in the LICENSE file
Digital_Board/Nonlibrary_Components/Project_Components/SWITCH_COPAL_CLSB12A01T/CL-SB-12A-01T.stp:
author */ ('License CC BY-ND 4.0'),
